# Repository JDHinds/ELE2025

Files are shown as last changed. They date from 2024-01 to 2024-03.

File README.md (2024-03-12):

# ELE2025 - Autonumous Line-Following Machine Project

## Weekly Design Report

### [David Gardiner](mailto:dgardiner04@qub.ac.uk)

| Image | Week | Progress |
|---|---|---|
|  | 16/01/24 | Met with team; |
| | 23/01/24 | Identification of errors from previous lab’s code and correction of wire placement from Arduino to Motor Driver Board to get motors operating correctly with PWM signals and button input.  Wiring of Encoder to Arduino and testing of code to check the serial monitor values increment with motor rotations. Carried out the Risk Assesment.|
| | 30/01/24 | Wiring of Encoder on second motor to Arduino and testing of code to check the serial monitor values increment with motor rotations for both motors.  Connection of battery instead of power supply to allow for wireless movement.  Research of Infrared Line Tracking Sensor to determine the wiring and potential code to be used.|
| | 06/02/24 | Wiring and coding of Infrared Line Tracking Sensor to detect a difference between white and black on a page.  Glued wheels and fitted stabilising wheel from old chassis onto new chassis.|
| | 13/02/24 | Reading Week.|
| | 20/02/24 | Building of new chassis and fitting of components.  IR Sensors working, and trial code uploaded to test on track.  Changed sensors to back and reversed motor direction in code to allow for more sharp cornering.|
| | 22/02/24 | Robot now completes the cornering section of the course.|
| | 27/02/24 | Adjustment of motor speeds to complete course faster.  Wiring and coding of encoder to allow motor speed to be monitored.|
| | 29/02/24 | IR Sensors fitted with screws and 2 additional sensors added.  Interrupt code added to enable outside sensors to enable the last used code to run when the line is overshot, allowing faster speeds to be achieved within course.|
| | 05/03/24 | Fixing of motors and wires after damage caused when stored, causing setbacks to progress.  Added 2 rail breadboard to provide additional 5V and Ground pins which can be accessed easily.  Code fixed and ball pushing code implemented with original line following code to enable the complete course to be completed in 18 seconds.  Soldering of wires to bluetooth module and wiring completed. |
| | 07/03/24 | Adjustment of motor speeds and adding speed restriction at end of course to allow more control for ball pushing section of course.  Autonomous mode is now complete. |
| | 08/03/24 | Wiring of Robot was tampered with and motors were removed and driving shafts broken.  Spent time identifing wiring issues. |
| | 11/03/24 | New motors fitted and testing of code implementation with Jude. |

### [Jude Hinds](mailto:jhinds04@qub.ac.uk)

| Image | Week | Progress |
|---|---|---|
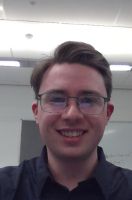
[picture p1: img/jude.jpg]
|  | 16/01/24 | Met with team; chosen as team leader; appointed as Programming Lead, and wrote the code for the tasks in the first lab. Was unable to verify code due to technical issues. |
| | 23/01/24 | Fixed code from last week's lab; wrote RotationUsingEncoder code. Carried out the Risk Assesment. |
| | 30/01/24 | Worked on Sensors Lab |
| | 06/02/24 | Reserched and Assembeled HC-05 Module. Discovered Flutter SerialPort library. |
| | 13/02/24 | Reading Week - was occupied with other assignments |
| | 20/02/24 | Made JSON Serialisable class for reading data in and out of the serial monitor. Serial monitor cannot yet be read accurately. |
| | 27/02/24 | Flutter program now accurately read serial monitor. |
| | 05/03/24 | Program can now read and write states to the board. Now working on finalising line following algorithm w/ David. |

### [Oran Farrell](mailto:ofarrell03@qub.ac.uk)

| Image | Week | Progress |
|---|---|---|
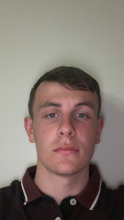
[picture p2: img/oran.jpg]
|  | 16/01/24 | Met with team; |
| | 30/01/24 | Began the design of the robot. Decided on a two tier, two wheel system with a stabliser wheel at the back. Have a basic schematic drawn out on paper, need to move this onto Fusion 360. | 
| | 05/02/24  | Completed a basic design mock-up on fusion 360. 2 basic panels, 150mm, 100mm, 5mm. Each panel has 4 holes located in corners 10mm in diameter. the bottom panel additional has a hole at the back, (30mm in diameter) which is for the stablising wheel. the pilers are 60mm tall and 10mm in diameter. |
| | 13/02/24 | Reading Week.|
| | 20/02/24 | Designed a wedge on CAD to attached to front two bars to help maneuver the ball into the set position at the end. |
| | 27/02/24 | Had to redesign the wedge as the sensors were hitting the ball. Left a larger gap to stop this problem. Started working towards the presentation.|
| | 05/03/24 | Continued working on the presentation. |

### [Conrad Quinn](mailto:cquinn167@qub.ac.uk)

| Image | Week | Progress |
|---|---|---|
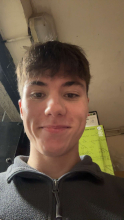
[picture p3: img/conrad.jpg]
|  | 16/01/24 | Met with team; |
| | 23/01/24 | Worked on the proportional control algorithm code using Arduino. |
| | 30/01/24 | Made a start on the code that will be used to implement the Infrared Sensors to help with the line tracking. |
| | 13/02/24 | This was a reading week so I was preoccupied with other work. |
| | 20/02/24 | Made a start on the presentation. Organised, using the github progress reports, what exactly we have added and contributed to the presentation and made a rough layout and a progress tracker to ensure it is finished with appropriate time. |
| | 27/02/24 | Continued working on the presentation, updated slides based on the progress our group has made and included a slide that describes problems we have faced on the project and will explain during the presentation how we overcame these. |
| | 05/03/24 | Worked with the group to improve our timing and to get it lower than the 18 seconds that we were achieving. Worked with the group to help improve the ball-pushing at the end of the track to ensure it was as accurate as possibe. Continued to work on the presentation to include pictures of the robot to aid in the understanding of what exactly was being explained in the presentation. Made the presentation more visually appealing and interesting to keep interest. |
| | 12/03/24 | Met with group for final work-through of the robot before the demo. Updated the presentation to be in line with the updated version of the robot, with the addition of the new wedge. Continued to work on the presentation and enabled access to the group to enable the video recording of each member. |

# To-Do

- [ ] Make shell for board
- [ ] Get and integrate sensors

- [ ] Write Arduino code for Line-Following
- [ ] Write Arduino code for ball pushing
- [ ] Write Ardiuno Code for HC-05 module
- [ ] Write application to interface with HC-05
  - [ ] Getting and displaying telemetrics

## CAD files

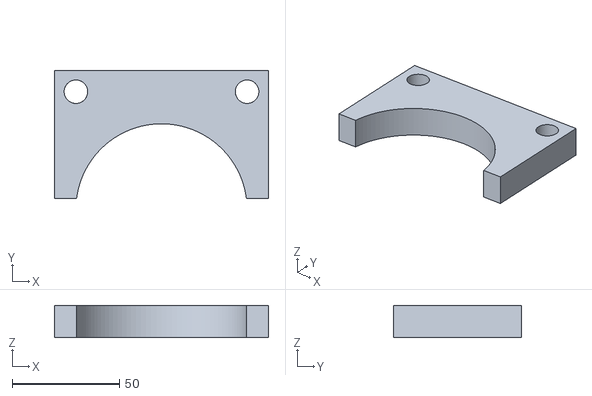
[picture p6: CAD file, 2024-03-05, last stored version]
wedge 2.0 v1.stl
100.0 x 60.0 x 15.0

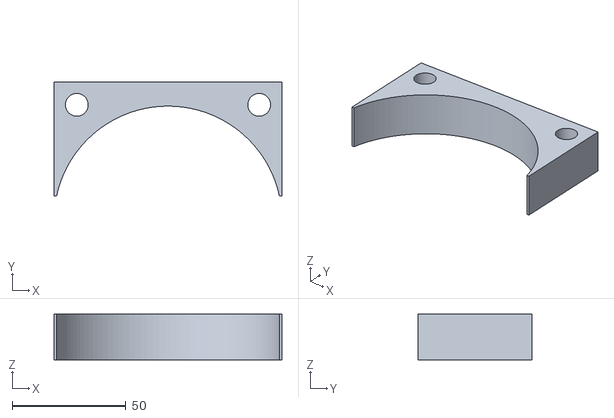
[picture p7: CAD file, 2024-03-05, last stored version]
Front Wedge v1.stl
100.0 x 50.0 x 20.0

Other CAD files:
Piller v1.f3d
bottom plate v1.f3d
img/Piller v1.f3d
img/bottom plate v1.f3d
img/top plate v1.f3d
top plate v1.f3d

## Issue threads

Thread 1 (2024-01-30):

JD's Phone Charger

jamie-54, 2024-01-30:
@JDHinds I have your phone charger

Thanks

Closed 2024-01-30.

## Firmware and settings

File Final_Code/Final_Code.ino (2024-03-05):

#define M1A 10 //M1A is connected to Arduino pin 2
#define M1B 11 //M1B is connected to Arduio pin 3
#define M2A 4 //M1A is connected to Arduino pin 4
#define M2B 5 //M1B is connected to Arduio pin 5

#define rightSesnor1 6
#define leftSesnor1 7
#define rightSesnor2 2
#define leftSesnor2 3

#define APin1 18
#define BPin1 19
#define APin2 20
#define BPin2 21

volatile unsigned long ACount1 = 0;
volatile unsigned long BCount1 = 0;
volatile unsigned long ACount2 = 0;
volatile unsigned long BCount2 = 0;

int mode = 1;

//attachInterrupt(digitalPinToInterrupt(APin1), ATick, RISING);

bool tr = false;
bool tl = false;

bool ok = true;

void setup() 
{
  Serial.begin(9600);
  attachInterrupt(digitalPinToInterrupt(rightSesnor2), tright, RISING);
  attachInterrupt(digitalPinToInterrupt(leftSesnor2), tleft, RISING);
  pinMode (M1A, OUTPUT);
  pinMode (M1B, OUTPUT);
  
  pinMode (M2A, OUTPUT);
  pinMode (M2B, OUTPUT);  

  pinMode(APin1, INPUT);
  pinMode(BPin1, INPUT);
  pinMode(APin2, INPUT);
  pinMode(BPin2, INPUT);

  attachInterrupt(digitalPinToInterrupt(APin1), ATick1, RISING);
  attachInterrupt(digitalPinToInterrupt(BPin1), BTick1, RISING);
  attachInterrupt(digitalPinToInterrupt(APin2), ATick2, RISING);
  attachInterrupt(digitalPinToInterrupt(BPin2), BTick2, RISING);
}

void loop() 
{  

  if(mode == 1)
  {
    lineFollowing();
  }

  else if(mode == 2)
  {
    ballPushing();
  }    
}


void lineFollowing()
{
    bool leftSensor1Value = digitalRead(leftSesnor1);
    bool rightSensor1Value = digitalRead(rightSesnor1); 


   if(leftSensor1Value == HIGH && rightSensor1Value == HIGH)
   {    
     mode = 2;  
     ACount1 = 0;
   }    
  
    if(leftSensor1Value)
    {
      tl=false;
    }
    if(rightSensor1Value)
    {
      tr=false;
    }
  
    if((leftSensor1Value == LOW  && rightSensor1Value == LOW) && (tr == false && tl == false))
    {
      int motor1Speed = 190;
      int motor2Speed = 190;
      
      //Both White
  
      analogWrite(M1A, 0); //Set M1A to ~10% PWM signal
      analogWrite(M1B, motor1Speed); //Set M1B to 0
  
      analogWrite(M2A, 0); //Set M2A to ~10% PWM signal
      analogWrite(M2B, motor2Speed); //Set M2B to 0
    }
  
    else if((leftSensor1Value == LOW && rightSensor1Value == HIGH)||(tl == true))
    {
      int motor1Speed = 80;
      int motor2Speed = 40;
      
      //Left Black and Right White
      
      analogWrite(M1A, 0); //Set M1A to ~10% PWM signal
      analogWrite(M1B, motor1Speed); //Set M1B to 0
  
      analogWrite(M2A, motor2Speed); //Set M2A to ~10% PWM signal
      analogWrite(M2B, 0); //Set M1B to 0
    }
  
    else if((leftSensor1Value == HIGH && rightSensor1Value == LOW)||(tr == true))
    {
      int motor1Speed = 40;
      int motor2Speed = 80;
    
      //Left White and Right Black

     analogWrite(M1A, motor1Speed); //Set M1A to ~10% PWM signal
     analogWrite(M1B, 0); //Set M1B to 0

     analogWrite(M2A, 0); //Set M2A to ~10% PWM signal
     analogWrite(M2B, motor2Speed); //Set M2B to 0
   }  
}

void ballPushing()
{
    
  if(ACount1 < 1600)
  {
      int motor1Speed = 60;
      int motor2Speed = 60;
  
      analogWrite(M1A, 0); //Set M1A to ~10% PWM signal
      analogWrite(M1B, motor1Speed); //Set M1B to 0
  
      analogWrite(M2A, 0); //Set M2A to ~10% PWM signal
      analogWrite(M2B, motor2Speed); //Set M2B to 0        
  }

  else if(ACount1 < 3000)
  {
      int motor1Speed = 50;
      int motor2Speed = 50;
  
      analogWrite(M1A, motor1Speed); //Set M1A to ~10% PWM signal
      analogWrite(M1B, 0); //Set M1B to 0
  
      analogWrite(M2A, motor2Speed); //Set M2A to ~10% PWM signal
      analogWrite(M2B, 0); //Set M2B to 0
  }

  else
  {
      analogWrite(M1A, 0); //Set M1A to ~10% PWM signal
      analogWrite(M1B, 0); //Set M1B to 0
  
      analogWrite(M2A, 0); //Set M2A to ~10% PWM signal
      analogWrite(M2B, 0); //Set M2B to 0
  }
}

void tleft()
{
  tl = true;
  tr = false;
    
}

void tright()
{  
    tr = true;
    tl = false;
}

void ATick1()
{
    ACount1++;
}
void BTick1()
{
    BCount1++;
}

void ATick2()
{
    ACount2++;
}
void BTick2()
{
    BCount2++;
} 

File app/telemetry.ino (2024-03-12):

#include <ArduinoJson.h>

#define M1A 10 //M1A is connected to Arduino pin 2
#define M1B 11 //M1B is connected to Arduio pin 3
#define M2A 4 //M1A is connected to Arduino pin 4
#define M2B 5 //M1B is connected to Arduio pin 5

#define rightSesnor1 6
#define leftSesnor1 7
#define rightSesnor2 2
#define leftSesnor2 3

#define APin1 18
#define BPin1 19
#define APin2 20
#define BPin2 21

volatile unsigned long ACount1 = 0;
volatile unsigned long BCount1 = 0;
volatile unsigned long ACount2 = 0;
volatile unsigned long BCount2 = 0;

int mode = 0;
int telemode = 0;

bool tr = false;
bool tl = false;

bool ok = true;

char JsonOutput[192];

class TelemetryData
{
  public:
    bool connected;
    int leftWheelSpeed;
    int rightWheelSpeed;
    bool isLeftSensorDark;
    bool isRightSensorDark;
    int distanceTravelled; 
};

TelemetryData data;

void setup() 
{
  Serial.begin(115200);
  Serial.setTimeout(500);
  attachInterrupt(digitalPinToInterrupt(rightSesnor2), tright, RISING);
  attachInterrupt(digitalPinToInterrupt(leftSesnor2), tleft, RISING);
  pinMode (M1A, OUTPUT);
  pinMode (M1B, OUTPUT);
  
  pinMode (M2A, OUTPUT);
  pinMode (M2B, OUTPUT);  

  pinMode(APin1, INPUT);
  pinMode(BPin1, INPUT);
  pinMode(APin2, INPUT);
  pinMode(BPin2, INPUT);

  attachInterrupt(digitalPinToInterrupt(APin1), ATick1, RISING);
  attachInterrupt(digitalPinToInterrupt(BPin1), BTick1, RISING);
  attachInterrupt(digitalPinToInterrupt(APin2), ATick2, RISING);
  attachInterrupt(digitalPinToInterrupt(BPin2), BTick2, RISING);
}

void loop() 
{  
  if(mode == 1)
  {
    lineFollowing();
    Serial.print(String(telemode));
  }

  else if(mode == 2)
  {
    ballPushing();
    Serial.print(String(telemode));
  }    
  else
  {
    recieveInstructions();
  } 
}


void lineFollowing()
{
    bool leftSensor1Value = digitalRead(leftSesnor1);
    bool rightSensor1Value = digitalRead(rightSesnor1); 


   if(leftSensor1Value == HIGH && rightSensor1Value == HIGH)
   {    
     mode = 2;  
     ACount1 = 0;
   }    
  
    if(leftSensor1Value)
    {
      tl=false;
    }
    if(rightSensor1Value)
    {
      tr=false;
    }
  
    if((leftSensor1Value == LOW  && rightSensor1Value == LOW) && (tr == false && tl == false))
    {

      int motor1Speed = 0;
      int motor2Speed = 0;
      
      if(ACount1 < 15000)
      {
         motor1Speed = 220;
         motor2Speed = 220;
         
         data.connected = true;
         data.leftWheelSpeed = 220;
         data.rightWheelSpeed = 220;
         data.isLeftSensorDark = false;
         data.isRightSensorDark = false;
         data.distanceTravelled = ACount2;

         telemode = 0;
      }

      else
      {
         motor1Speed = 90;
         motor2Speed = 90;

         data.connected = true;
         data.leftWheelSpeed = 90;
         data.rightWheelSpeed = 90;
         data.isLeftSensorDark = false;
         data.isRightSensorDark = false;
         data.distanceTravelled = ACount2;

        telemode = 1;
      }
      
      
      
      //Both White
  
      analogWrite(M1A, 0); //Set M1A to ~10% PWM signal
      analogWrite(M1B, motor1Speed); //Set M1B to 0
  
      analogWrite(M2A, 0); //Set M2A to ~10% PWM signal
      analogWrite(M2B, motor2Speed); //Set M2B to 0
    }
  
    else if((leftSensor1Value == LOW && rightSensor1Value == HIGH)||(tl == true))
    {
      int motor1Speed = 70;
      int motor2Speed = 60;
      
      //Left Black and Right White
      
      analogWrite(M1A, 0);
      analogWrite(M1B, motor1Speed);
  
      analogWrite(M2A, motor2Speed);
      analogWrite(M2B, 0);

      data.connected = true;
      data.leftWheelSpeed = -70;
      data.rightWheelSpeed = 60;
      data.isLeftSensorDark = true;
      data.isRightSensorDark = false;
      data.distanceTravelled = ACount2;

      telemode = 2;
    }
  
    else if((leftSensor1Value == HIGH && rightSensor1Value == LOW)||(tr == true))
    {
      int motor1Speed = 60;
      int motor2Speed = 70;
    
      //Left White and Right Black

     analogWrite(M1A, motor1Speed);
     analogWrite(M1B, 0);

     analogWrite(M2A, 0);
     analogWrite(M2B, motor2Speed);

      data.connected = true;
      data.leftWheelSpeed = 60;
      data.rightWheelSpeed = -70;
      data.isLeftSensorDark = false;
      data.isRightSensorDark = true;
      data.distanceTravelled = ACount2;

      telemode = 3;
   }  
}

void ballPushing()
{
    
  if(ACount1 < 1900)
  {
      int motor1Speed = 70;
      int motor2Speed = 70;
  
      analogWrite(M1A, 0);
      analogWrite(M1B, motor1Speed);
  
      analogWrite(M2A, 0);
      analogWrite(M2B, motor2Speed);

      data.connected = true;
      data.leftWheelSpeed = 70;
      data.rightWheelSpeed = 70;
      data.isLeftSensorDark = false;
      data.isRightSensorDark = false;
      data.distanceTravelled = ACount2;

      telemode = 4;
  }

  else if(ACount1 < 3000)
  {
      int motor1Speed = 100;
      int motor2Speed = 100;
  
      analogWrite(M1A, motor1Speed);
      analogWrite(M1B, 0);
  
      analogWrite(M2A, motor2Speed);
      analogWrite(M2B, 0);
      
      data.connected = true;
      data.leftWheelSpeed = 100;
      data.rightWheelSpeed = 100;
      data.isLeftSensorDark = false;
      data.isRightSensorDark = false;
      data.distanceTravelled = ACount2;

      telemode = 5;
  }

  else
  {
      analogWrite(M1A, 0);
      analogWrite(M1B, 0);
  
      analogWrite(M2A, 0);
      analogWrite(M2B, 0);

      data.connected = true;
      data.leftWheelSpeed = 0;
      data.rightWheelSpeed = 0;
      data.isLeftSensorDark = false;
      data.isRightSensorDark = false;
      data.distanceTravelled = ACount2;

      telemode = 6;
  }
}

void serialiseData(TelemetryData data)
{
  JsonDocument doc;
  doc["connected"] = true;
  doc["leftWheelSpeed"] = data.leftWheelSpeed;
  doc["rightWheelSpeed"] = data.rightWheelSpeed;
  doc["isLeftSensorDark"] = data.isLeftSensorDark;
  doc["isRightSensorDark"] = data.isRightSensorDark;
  doc["distanceTravelled"] = data.distanceTravelled;

  serializeJson(doc, JsonOutput);
}

void serialiseShortData(TelemetryData data)
{
  JsonDocument doc;
  doc["c"] = true;
  doc["LW"] = data.leftWheelSpeed;
  doc["RWS"] = data.rightWheelSpeed;
  doc["LS"] = data.isLeftSensorDark;
  doc["RS"] = data.isRightSensorDark;
  doc["d"] = data.distanceTravelled;

  serializeJson(doc, JsonOutput);
}

void deserialiseData(String input)
{
  JsonDocument doc;
  deserializeJson(doc, input);

  data.connected = doc["connected"];
  data.leftWheelSpeed = doc["leftWheelSpeed"];
  data.rightWheelSpeed = doc["rightWheelSpeed"];
  data.isLeftSensorDark = doc["isLeftSensorDark"];
  data.isRightSensorDark = doc["isRightSensorDark"];
  data.distanceTravelled = doc["distanceTravelled"];
}

/*void sendTelemetry()
{
  serialiseShortData(data);
  String output = String(JsonOutput);
  for (int i = 0; i < output.length(); i += 8)
  { Serial.print(output.substring(i,i+8)); delay(10);}
}*/
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

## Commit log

2024-01-23 Fixed Last Week's Code
    [coasting.ino, linearAcceleration.ino]
2024-01-30 Added Basic App & Fixed Typo
    [main.cpp]
2024-02-05 Create Fusion 360 CAD Designs.
